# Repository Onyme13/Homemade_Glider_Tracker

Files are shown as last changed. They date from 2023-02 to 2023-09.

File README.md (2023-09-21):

# Homemade Glider Computer (Work in progress)

In the world of light aviation and air sports, gliders occupy a special place because of their dependence on the weather and their ability to slide silently across the skies. To improve the flying experience of gliders and provide pilots with essential data in real time, My bachelor’s degree research project in Information Systems and Service Science focused on the design and implementation of a prototype homemade flight tracker specifically designed for these aircraft.

**WARNING: PROTOTYPE**

This device is an experimental prototype and should only be used for testing purposes. It is not intended for flight-critical applications or navigation. Use at your own risk. The creator is not responsible for any accidents or damages resulting from its use. Prioritize safety and follow all aviation regulations during testing.

## Installation

**Step 1: Gather the Required Materials**

Before starting the installation process, make sure you have all the necessary materials and components for your homemade glider computer. These may include:

1. Raspberry Pi Zero W (the WiFi model in important for ssh connection for future installations)
2. MicroSD card (at least 32GB)
3. Arduino Micro without headers
4. GPS Module
5. Antenna for the GPS module (not mandatory)
6. Barometric sensor
7. Display (TFT screen 3.5")
8. PiSugar Battery for Raspberry Pi-Zero W/WH 1200 mAh
9. Cables and connectors
10. micro-USB to micro-USB cable
11. Case to mount the components securely (Can be 3D printed).
    You can find the .stl file for the case and the cover on this repository.
(12. Two 2mm screws for closing the case, if 3D printed)

See the [Required Materials](https://github.com/Onyme13/Homemade_Glider_Tracker/tree/main/Documentation) for more informations about all the necessary materials.

**Step 2: Set Up the Raspberry Pi**

For more information. Follow the [Manuel_de_reproduction_FR.pdf](https://github.com/Onyme13/Homemade_Glider_Tracker/blob/main/Documentation/Manuel_de_reproduction_FR.pdf) for more details. Pages 6 to 11

1. Download the latest Raspberry Pi OS Imager from the official website.
2. Flash the OS image onto a microSD. In the Advanced option, enable SSH for remote connection. It is the only way to access to the Pi.
3. Download Advanced IP Scanner from the official website.
4. Download PuTTY - a free SSH and telnet client for Windows. (Or any other SSH solution)
5. Download FileZilla - The free File Transfert Protocol solution. You need this to upload your GPS map to the Pi.
5. Setup the Raspeberry Pi OS . Follow the [Manuel_de_reproduction_FR.pdf] guide. Pages 7 to 10
6. Insert the microSD card into the Raspberry Pi.

**Step 3: Install Required Software on the Raspberry PI using SSH**

For more information. Follow the [Manuel_de_reproduction_FR.pdf](https://github.com/Onyme13/Homemade_Glider_Tracker/blob/main/Documentation/Manuel_de_reproduction_FR.pdf) for more details. Pages 12 to 17

(This is probably the longest step of the installation)

1. Power up the Raspberry Pi.

2. Scan all the IP's from your network with Advanced IP Scanner so you can the Raspberry Pi's IP address.

3. With the now found IP adress. Connect to your Raspberry Pi through SSH with PuTTY. 

4. Update the Raspberry Pi OS by running:
   ```
   sudo apt-get update
   sudo apt-get upgrade
   ```

5. Clone the git repository by running.
    ```
    git clone https://github.com/Onyme13/Homemade_Glider_Tracker.git
    ```
6. Install Pip and go in to the file. After installation of pip, you can verify that pip is installed:
    ```
    sudo apt install python3-pip
    pip --version
    ```

   Then install the needed python libraries:

    ```
    cd Research-Project
    sudo python -m pip install -r requirements.txt
    ```    

7. File transfert the map zipped file using FileZilla (this step can take more than hour).

8. Unzip the file by running on the Raspberry Pi (this step can take more than hour):
    ```
    sudo apt install unzip
    unzip tile_OSM.zip
    ```
9. Meanwhile configure the screen by activating SPI connection on the Pi and disable Sleep Mode , run:
    ``` 
    sudo raspi-config
    ```
10. Navigate to Display Options, and press enter.
11. Navigate to the 4th line, Screen Blanking. Press Enter and select No. [link](https://raspberrytips.com/disable-sleep-mode-raspberry-pi/)
12. Activate the SPI connection on the same menu.
13. Then run:
    ```
    sudo rm -rf LCD-show
    git clone https://github.com/MrYacha/LCD-show.git
    chmod -R 755 LCD-show
    cd LCD-show/
    ```
    and 
    ```
    sudo ./LCD35-show
    ```
    The Pi will reboot, the screen should be correctly configured

**Step 4: Set Up the Microcontroller Arduino Micro**

1. Download the Arduino IDE from the official website
2. Connect your microcontroller to your computer with USB
3. Upload the Arduino_Double_Sensor.ino from this repository on the Arduino Micro with the Arduino IDE using your computer.

**Step 5: Assemble the Components**
Carefully solder all the connectors following the schema. Adapt the cabling according to your components.

Follow the [Manuel_de_reproduction_FR.pdf](https://github.com/Onyme13/Homemade_Glider_Tracker/blob/main/Documentation/Manuel_de_reproduction_FR.pdf) steps.

Double-check the schema (wiring diagram) to ensure you have a clear understanding of how the connectors should be soldered. The schema will show the connections between different components, such as sensors, displays, and microcontrollers.

Carefully mount the Raspberry Pi, microcontroller, sensors, display, and other components inside the case. 

**Step 6: Test the Glider Computer Software**

Verify that the software is working as expected. Make sure the data from sensors are accurate, the display shows the relevant information correctly, and the system behaves as intended.

**Step 7: Test the Glider Computer**

ALWAYS PRIORITIZE THE FLIGHT SAFETY.
KEEP YOUR EYES OUT OF THE PLANE.

Before the actual glider flight, do some ground tests to confirm that the glider computer works as expected. Once you're confident in its functionality, conduct a test flight to see how it performs during actual gliding.

**Step 8: Monitor and Improve**

ALWAYS PRIORITIZE THE FLIGHT SAFETY.
KEEP YOUR EYES OUT OF THE PLANE.

During and after the flight, closely monitor the glider computer's performance. Take note of any issues or improvements that can be made to enhance its functionality or accuracy.

Remember to always prioritize safety and adhere to local regulations.

## Contributing

Thank you for considering contributing to Homemade Glider Computer! I welcome contributions from the community and appreciate your support in making this project better.

1. Clone the repository

2. Make Changes

Make your desired changes and improvements to the codebase. Please ensure that your changes adhere to the project's coding standards and guidelines.

3. Test your Changes

Before submitting a pull request, make sure to test your changes thoroughly to ensure they work as intended and do not introduce any new issues.ct.

4. Commit your changes

5. Code Review

Your pull request will undergo a code review by the project maintainers. Be prepared to make additional changes based on feedback.

6. Merge

Once your pull request is approved and any necessary changes are made, it will be merged into the main project.

Thank you for your valuable contributions!

## License

This work is licensed under the Creative Commons Attribution-NonCommercial 4.0 International License. To view a copy of this license, visit https://creativecommons.org/licenses/by-nc/4.0/ or send a letter to Creative Commons, PO Box 1866, Mountain View, CA 94042, USA.

## Contact

For any questions, feel free to contact me at this email adress: jocorl@hotmailch

## Photos

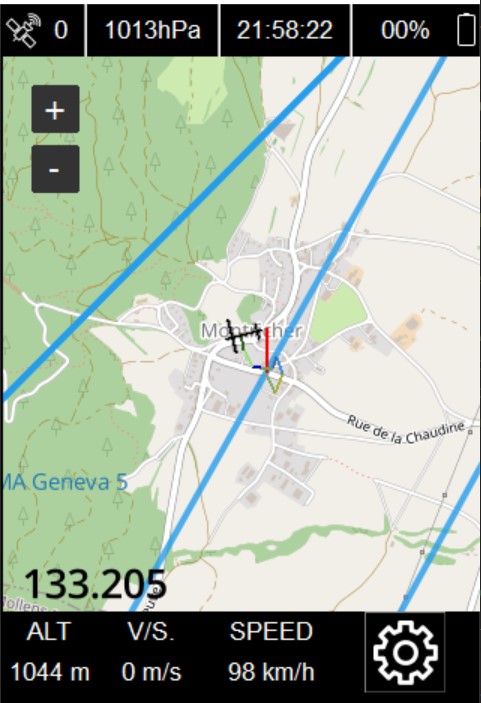
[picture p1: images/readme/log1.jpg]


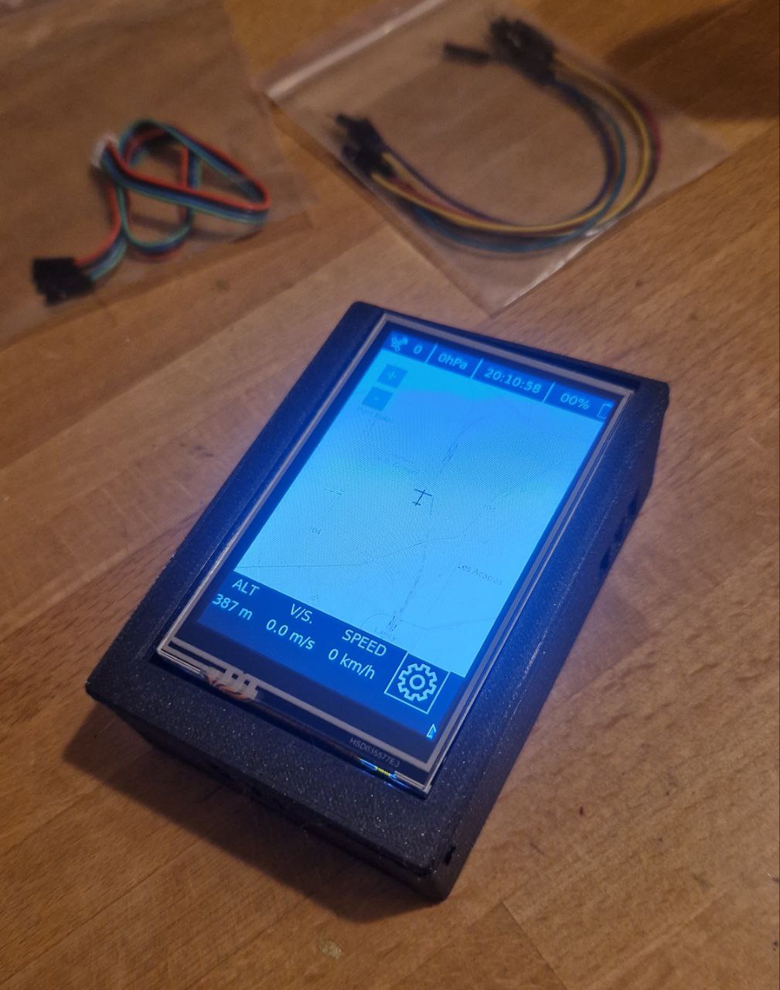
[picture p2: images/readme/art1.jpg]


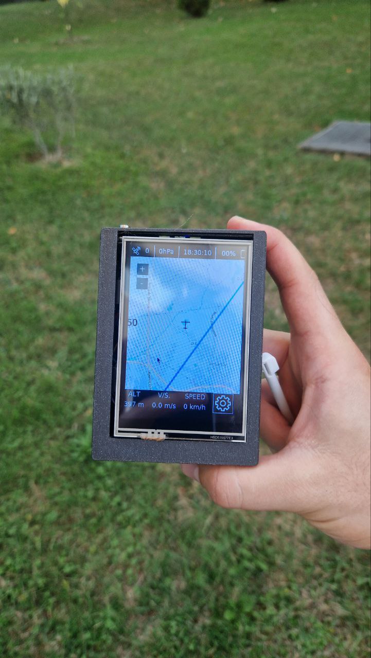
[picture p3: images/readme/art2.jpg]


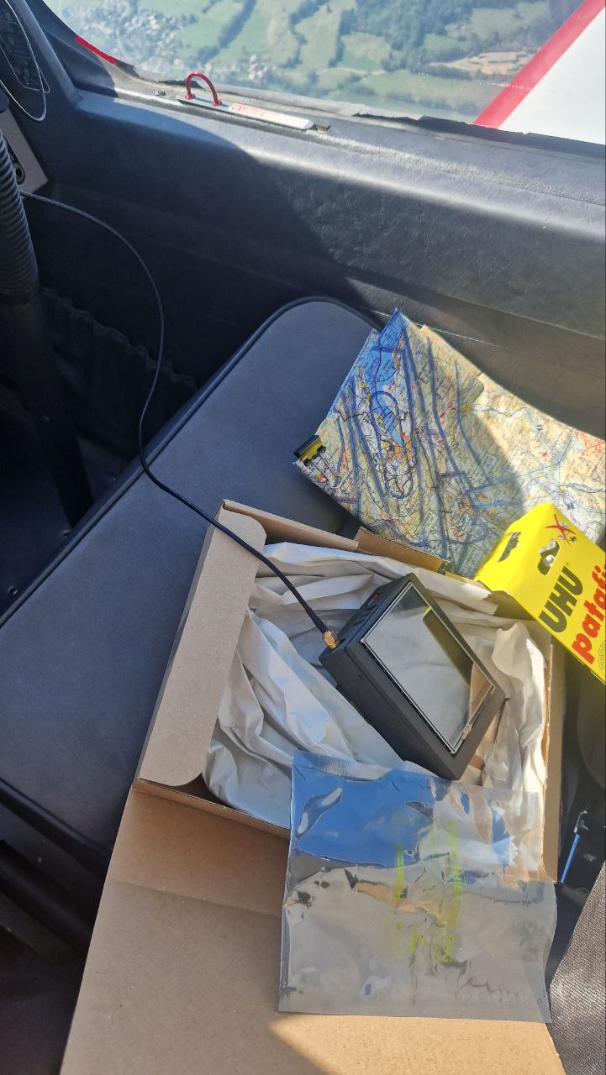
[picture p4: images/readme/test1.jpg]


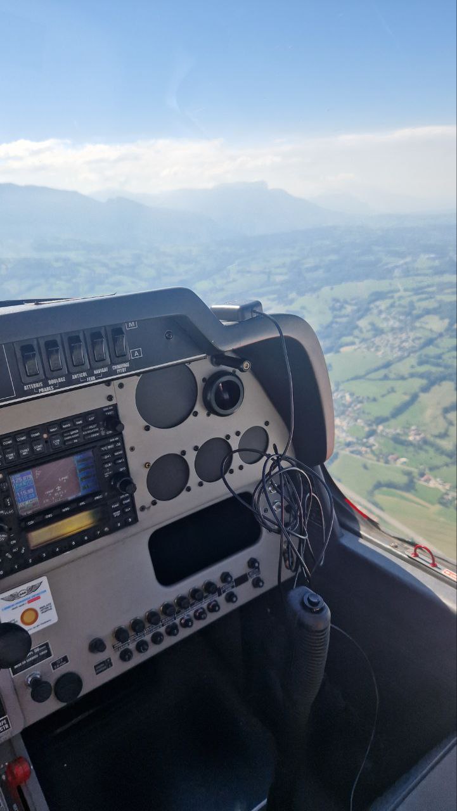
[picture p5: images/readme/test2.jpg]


## Further Reading

FacLab articles
1. [Développement d'un Tracker de Vol Fait Maison pour Planeurs](https://faclab.ch/publication/developpement-dun-tracker-de-vol-fait-maison-pour-planeurs)
2. [Tests et conclusion du travail de Bachelor du Tracker de Vol Fait Maison pour Planeurs](https://faclab.ch/publication/tests-et-conclusion-du-travail-de-bachelor-du-tracker-de-vol-fait-maison-pour-planeurs)

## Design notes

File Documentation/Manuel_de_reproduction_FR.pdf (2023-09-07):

# Manuel de reproduction tangible du tracker de vol à voile fait maison

# INDEX

Contenus

# Introduction

Dans le monde de l'aviation légère et des sports aériens, les planeurs occupent une place particulière en raison de leur dépendance à la météo et de leur capacité à glisser silencieusement à travers les cieux. Pour améliorer l'expérience de vol des planeurs et fournir aux pilotes des données essentielles en temps réel, mon projet de recherche de fin de bachelor en systèmes d’information et science des services s'est concentré sur la conception et la mise en œuvre d'un prototype de tracker de vol fait maison spécialement conçu pour ces aéronefs.

Les trackers de vol traditionnel que l’on trouve sur le marché sont relativement coûteux. Le prix de ces appareils se situe autour des 700 francs suisses. Grâce à la démocratisation des microcontrôleurs et microordinateur, ce travail de recherche se base sur la faisabilité de création d’un suiveur de vol fait maison.

Il faut avant tout commencé par choisir les composants appropriés, en tenant compte de facteurs tels que la taille, le poids, la consommation d'énergie et le prix. Les principaux éléments du tracker comprenaient un récepteur GPS, un baromètre et une unité centrale qui traite et stocke les données.

Ce manuel vous fournira les informations essentielles, les instructions détaillées et les astuces pratiques nécessaires pour mener à bien votre projet.

Dans les pages qui suivent, vous découvrirez les procédures étape par étape pour vous guider dans la réalisation du tracker de vol. Vous y trouverez des schémas, des illustrations, des listes de matériaux, et tout ce dont vous avez besoin pour reproduire.

Pour la partie code, référez vous au repo Git ci-dessous.

Lien du GitHub : https://github.com/Onyme13/Homemade_Glider_Tracker.git

# Préparation du Raspberry Pi Zero W

## Matériel

### 1. Raspberry Pi Zero W avec en-têtes (le modèle wifi est indispensable)

### 2. Carte microSD de 32Go minimum

## 1. Téléchargement des logiciel et le fichier requis sur votre PC

1.1 Advanced IP Scanner. Ce programme affiche toutes adresse IP des périphériques sur votre réseau :

https://www.advanced-ip-scanner.com/

1.2 Raspberry Pi Imager. Raspberry Pi Imager est le moyen rapide et facile d’installer Raspberry Pi OS sur une carte microSD, prête à l’emploi avec votre Raspberry Pi :

https://www.raspberrypi.com/software/

1.3 PuTTY. Ce programme est un client SSH principalement utilisé pour se connecter à distance à des systèmes informatiques:

https://www.putty.org/

1.4 FilleZilla Client. C’est un programme de transfert de fichiers qui permet aux utilisateurs de gérer et de transférer des fichiers entre leur ordinateur local et une machine distante :

https://filezilla-project.org/

### 1.5 Téléchargement de carte sur Google Drive :

https://drive.google.com/file/d/1Afhucx_kdtul0cSf0_6vRhANw7dOtnIN/view?usp=sharing

## 2. Installation Raspberry Pi OS

2.1 Insérez la carte SD dans le lecteur de carte de votre ordinateur.

2.2 Ouvrir le logiciel Raspverry PI OS.

### 2.3 Choisir le bon OS

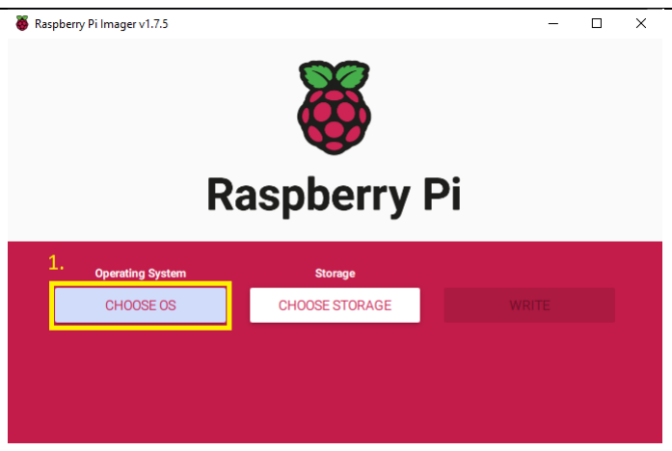
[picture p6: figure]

### 2.4 Choisir la carte microSD comme stockage

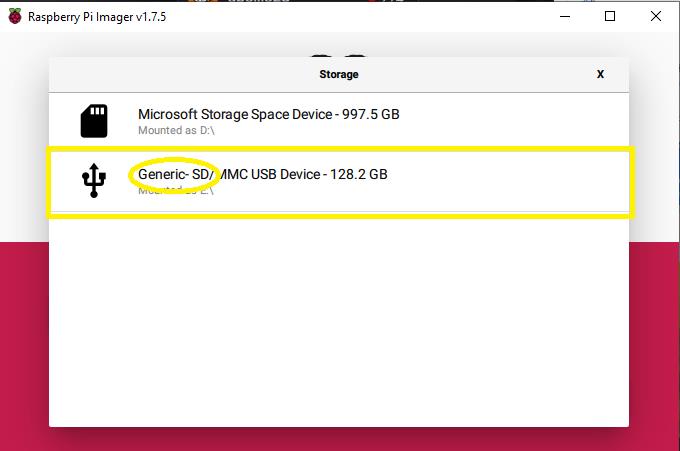
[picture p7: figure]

### 2.5.1 Configuration de l’OS

### 2.5.2 Activer le SSH et ajouter un Username et mot de passe

Sauvegarder l’identifiant et mot de passe pour l’étape Installation du logiciel sur Raspberry PI

### 2.5.3 Configurer la connexion au WiFi

1.Activer la connexion wLAN
2.Sélectionner le réseau local. Attention, le Raspberry Pi ne connecte pas au réseau de 5GHz
3.Entrer le mot du passe du réseau

### 2.5. Installer l’OS

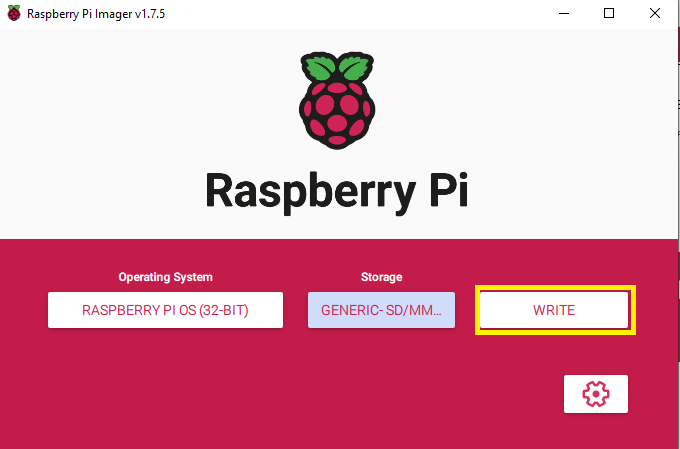
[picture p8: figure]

# Installation du logiciel sur le Raspberry PI

## 1. Insérer la carte microSD dans le Raspberry Pi

## 2. Allumer le Raspberry Pi

## 3. Trouver l’IP du Raspberry Pi

### 3.1 Lancer le scan avec Advanced IP Scanner

### 3.2 Copier l’IP du Raspberry PI

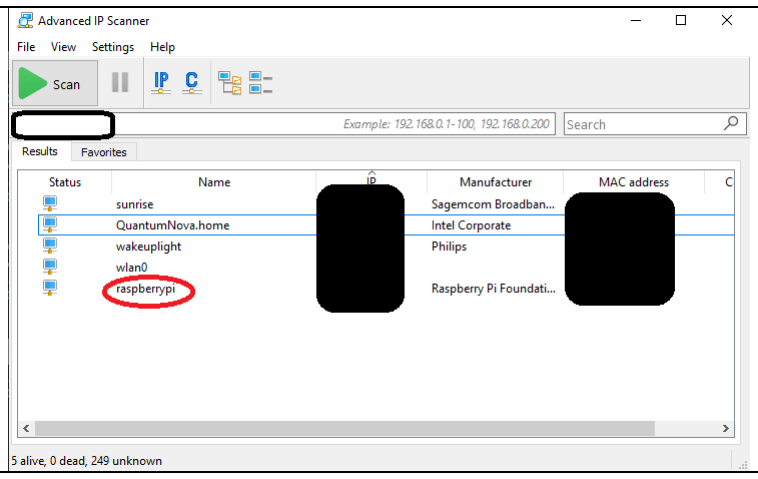
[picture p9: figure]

## 4. Connection via SSH

### 4.1 Ouvrir puTTY.exe

### 4.2 Connection au Raspberry Pi

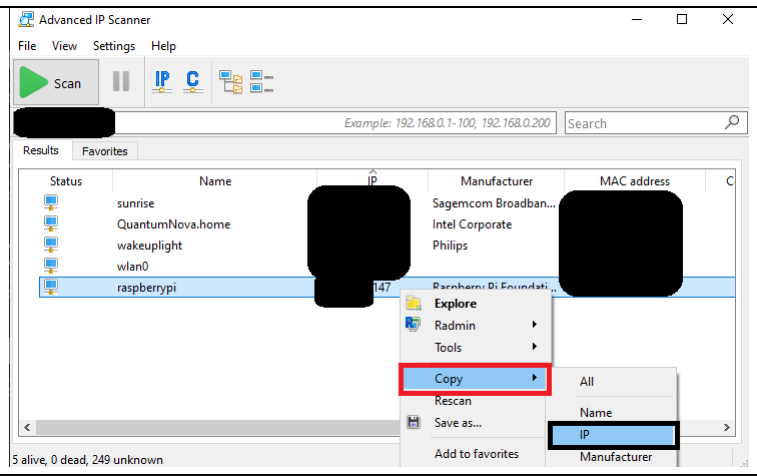
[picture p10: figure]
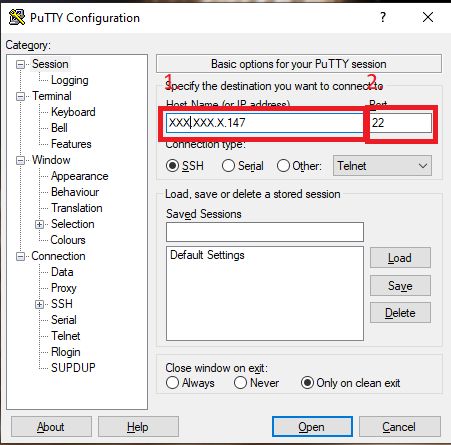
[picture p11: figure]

1. Coller l’IP du Raspberry Pi
2. Port 22 nécessaire

## 5. Téléchargement du logiciel

### 5.1 Connection au Raspberry avec les identifiants de l’étape Préparation du Raspberry Pi

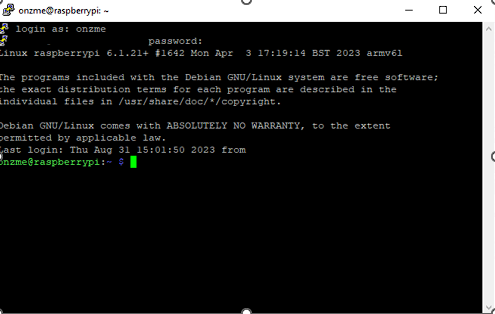
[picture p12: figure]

### 5.2 Mettre à jour le Raspberry Pi OS en exécutant

sudo apt-get update
sudo apt-get upgrade

### 5.3 Cloner le git repository en exécutant

git clone https://github.com/Onyme13/Homemade_Glider_Tracker.git

5.4 Installer Pip et aller dans le fichier et installer toutes les bibliothèques python nécessaires en exécutant :

sudo apt install python3-pip pip –version

5.5 Après l’installation de pip, vous pouvez vérifier que pip est installé. Ensuite, installez les bibliothèques python nécessaires

cd Homemade_Glider_Tracker sudo python -m pip install -r requirements.txt

5.6 Transférez le fichier zippé de la carte à l’aide de FileZilla.
Drag and Drop le dossier de la carte zippé de l’étape Préparation du Raspberry Pi

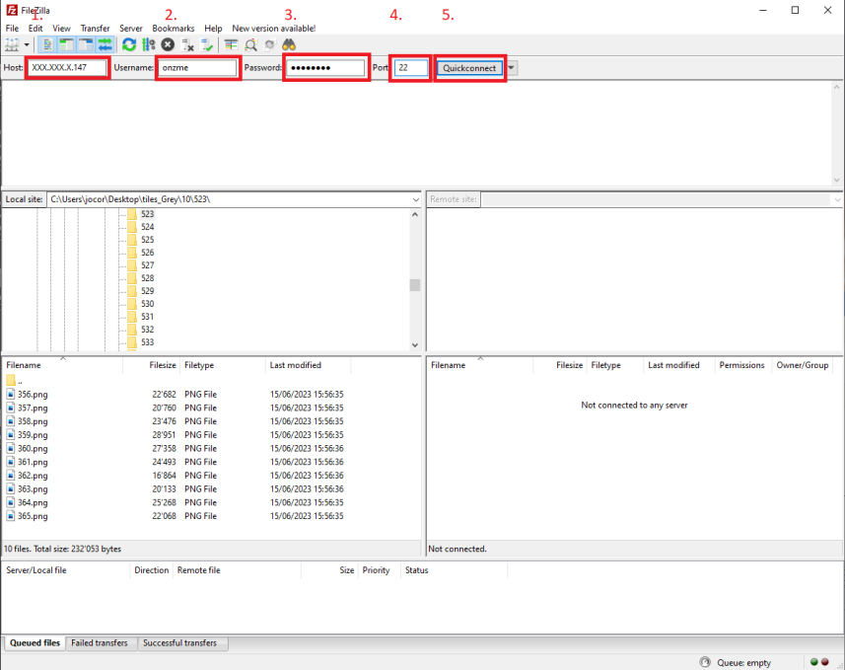
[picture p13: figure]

1. IP du Raspberry PI
2. Identifiant
3. Mot de passe
4. Port 22
5. Connection

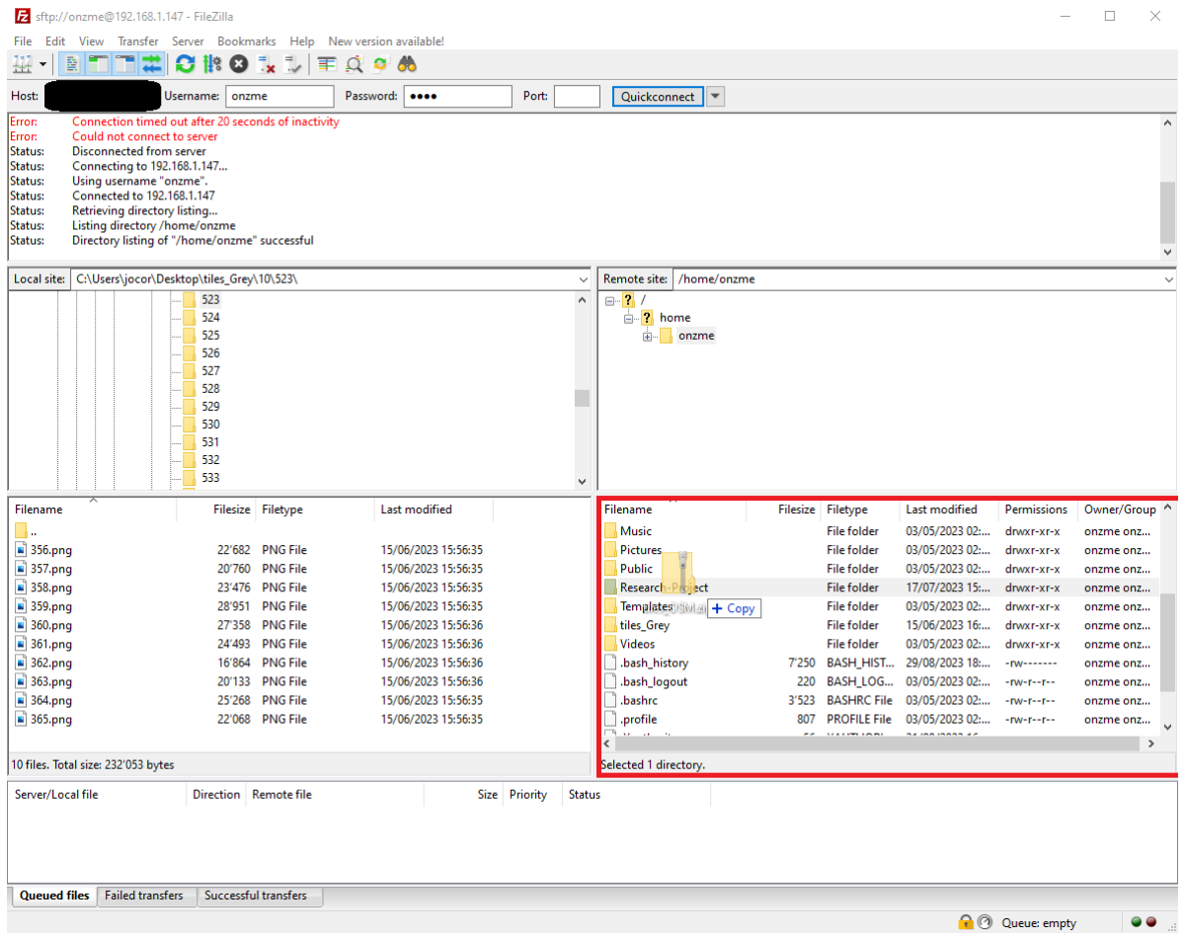
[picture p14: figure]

### 5.7 Décompressez le fichier en l’exécutant sur le Raspberry Pi en exécutant :

sudo apt install unzip
unzip tiles_OSM.zip

## 6. Activation du Touchscreen

### 6.1 Activer les connecteurs SPI

sudo raspi-config

6.2 Installer les fichiers nécessaire pour l’écran.

sudo rm -rf LCD-show
git clone https://github.com/MrYacha/LCD-show.git cd LCD-show
chmod LCD35-show

6.3 Finalement, le Raspberry Pi va redémarrer.

sudo ./LCD35-show

## 7. Ajout d’icône de lancement du logiciel sur le Desktop du Raspberry

Pi

### 7.1 Copie des données de l’icône sur le chemin du Desktop

cp Homemade_Glider_Tracker/launch.desktop ~/Desktop/

### 7.2 Ajout des droits d’exécution du script

sudo chmod +x Homemade_Glider_Tracker/startup.sh

# Assemblage du suiveur de vol

## Matériel

1. Module GPS - Whadda WPI430 Module GPS U-BLOX NEO-7M

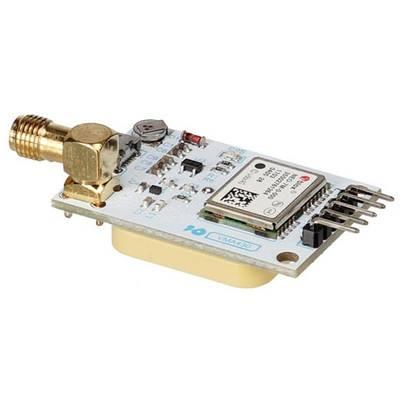
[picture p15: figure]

2. Module Baromètre - DFRobot Gravity BMP388 Capteur de pression barométrique

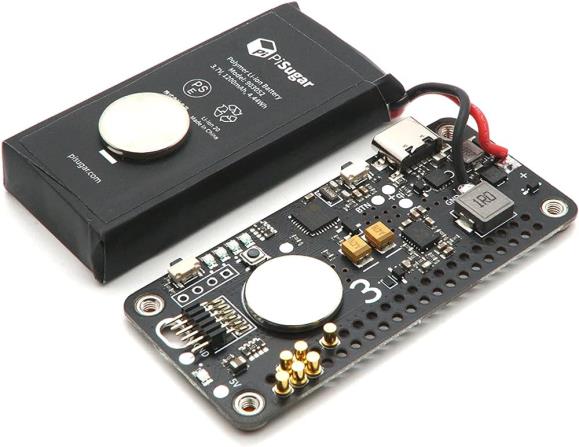
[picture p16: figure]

3. Batterie PiSugar - PiSugar Pwnagotchi Batterie au lithium pour Raspberry Pi-Zero W/WH 1200 mAh

4. Arduino Micro (sans les pins/headers)
5. Câbles DuPont

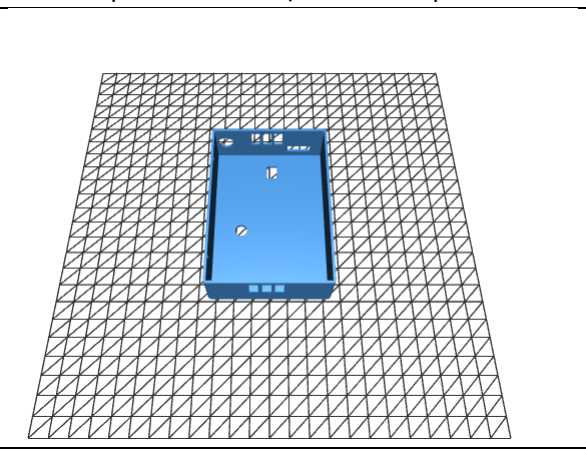
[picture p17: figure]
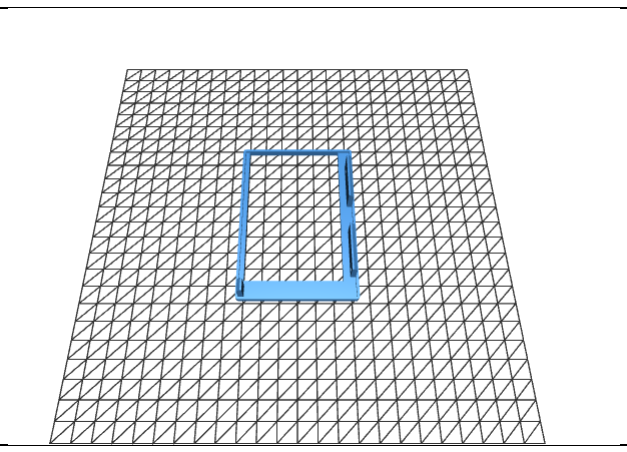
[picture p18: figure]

6. Boîter imprimer en 3D (voir les étapes suivantes)

## 1.Impression du boîter et de son couvercle en 3D

Fichier STL pour l’impression

- Boîtier :
https://github.com/Onyme13/Homemade_Glider_Tracker/blob/main/3D%20STL%20file/case%20v0. 2.stl (https://github.com/Onyme13/Homemade_Glider_Tracker/blob/main/3D%20STL%20file/case%20v0.2.stl)
- Couvercle :
https://github.com/Onyme13/Homemade_Glider_Tracker/blob/main/3D%20STL%20file/cover%20v0 .4.stl (https://github.com/Onyme13/Homemade_Glider_Tracker/blob/main/3D%20STL%20file/cover%20v0.4.stl)

## 2. Assemblage des câbles du Dupont sur le module GPS

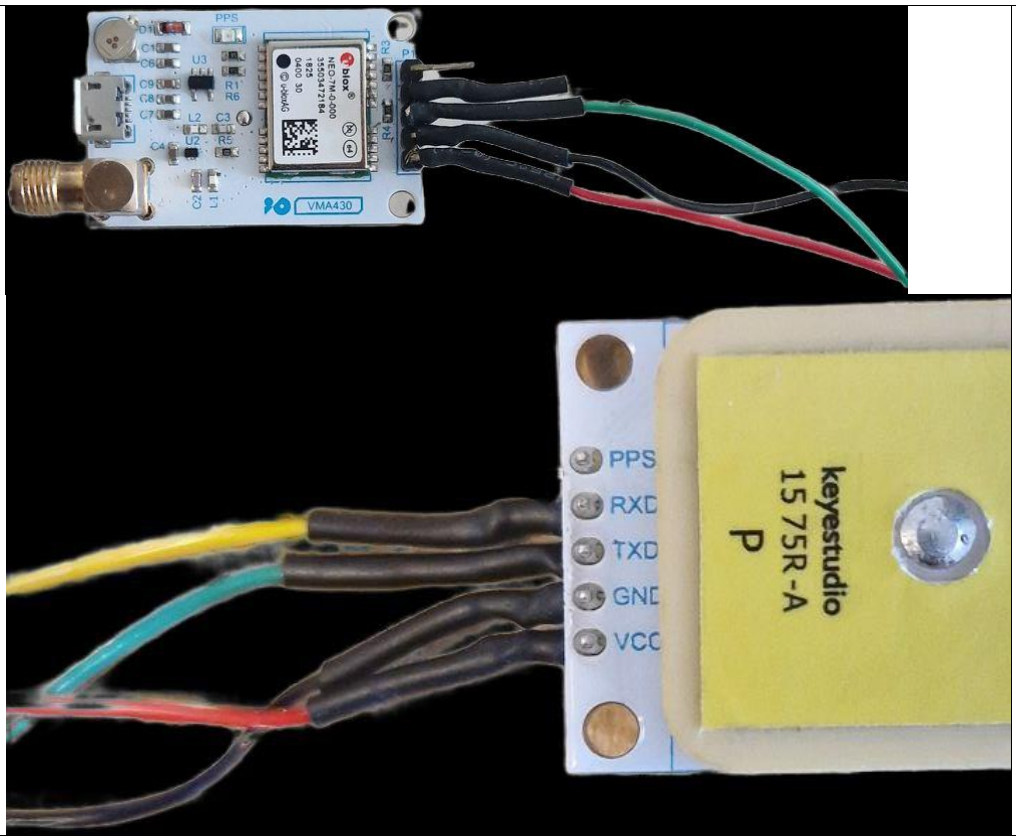
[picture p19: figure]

- RXD transmission câble jaune
- TXD transmission câble vert
- GND prise de terre câble noir
- VCC entrée 5 v câble rouge

## 3. Assemblage des câbles du Dupont sur le module barométrique

Souder les câbles Dupont aux entrées :
- VCC
- GND
- SDO
- CSB
- SDI
- SCK

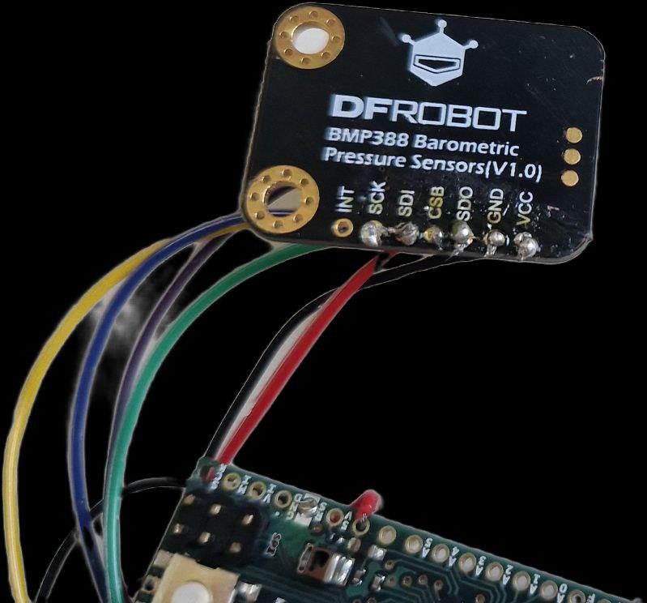
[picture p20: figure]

## 4. Assemblage des câbles du GPS et baromètre au Arduino Micro

Souder les câbles du GPS et du baromètres au Arduino Micro comme suit :

Baromètre :
- VCC → +3.3V
- GND → GND
- SDO → 12
- CSB → 10
- SDI → 11
- SCK → 13

Module GPS :

- VCC → +5V
- GND → GND
- RXD → 9
- TXD → 8

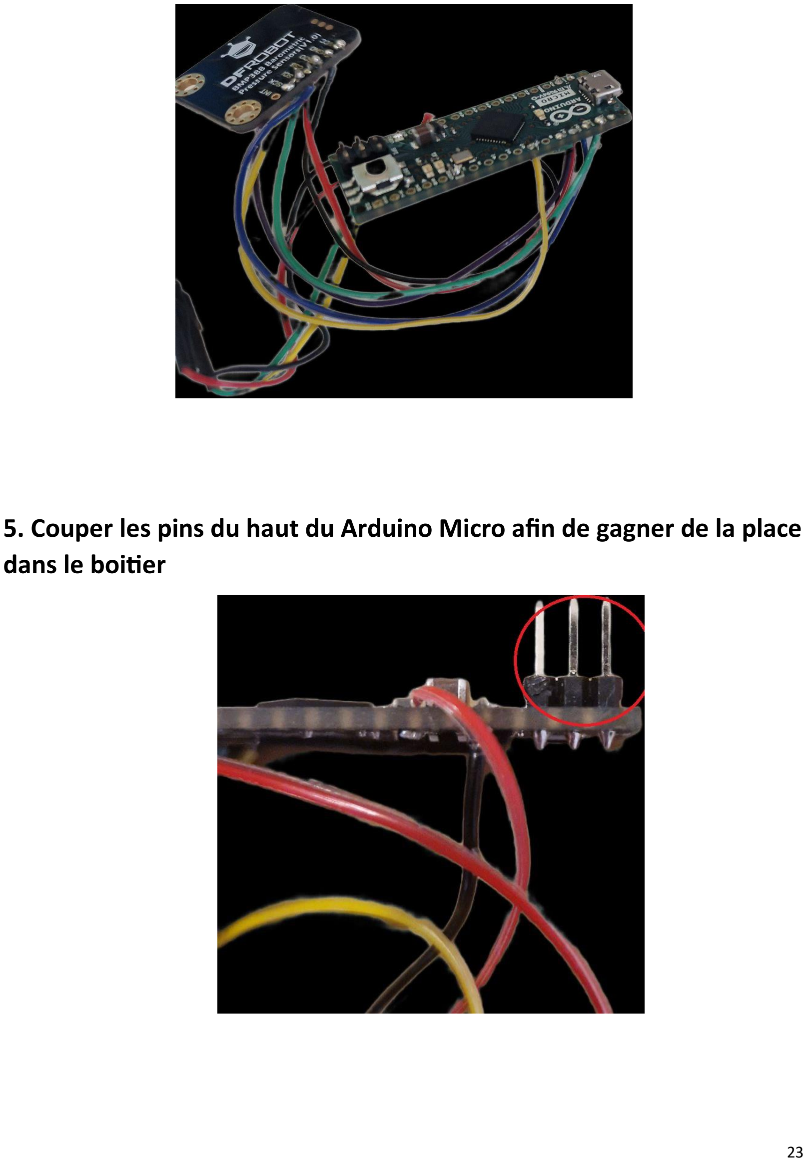
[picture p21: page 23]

## 5. Couper les pins du haut du Arduino Micro afin de gagner de la place dans le boitier

## 6.Branchez la batterie PiSugar sur le Raspberry Pi à l’aide des quatre vis fournies

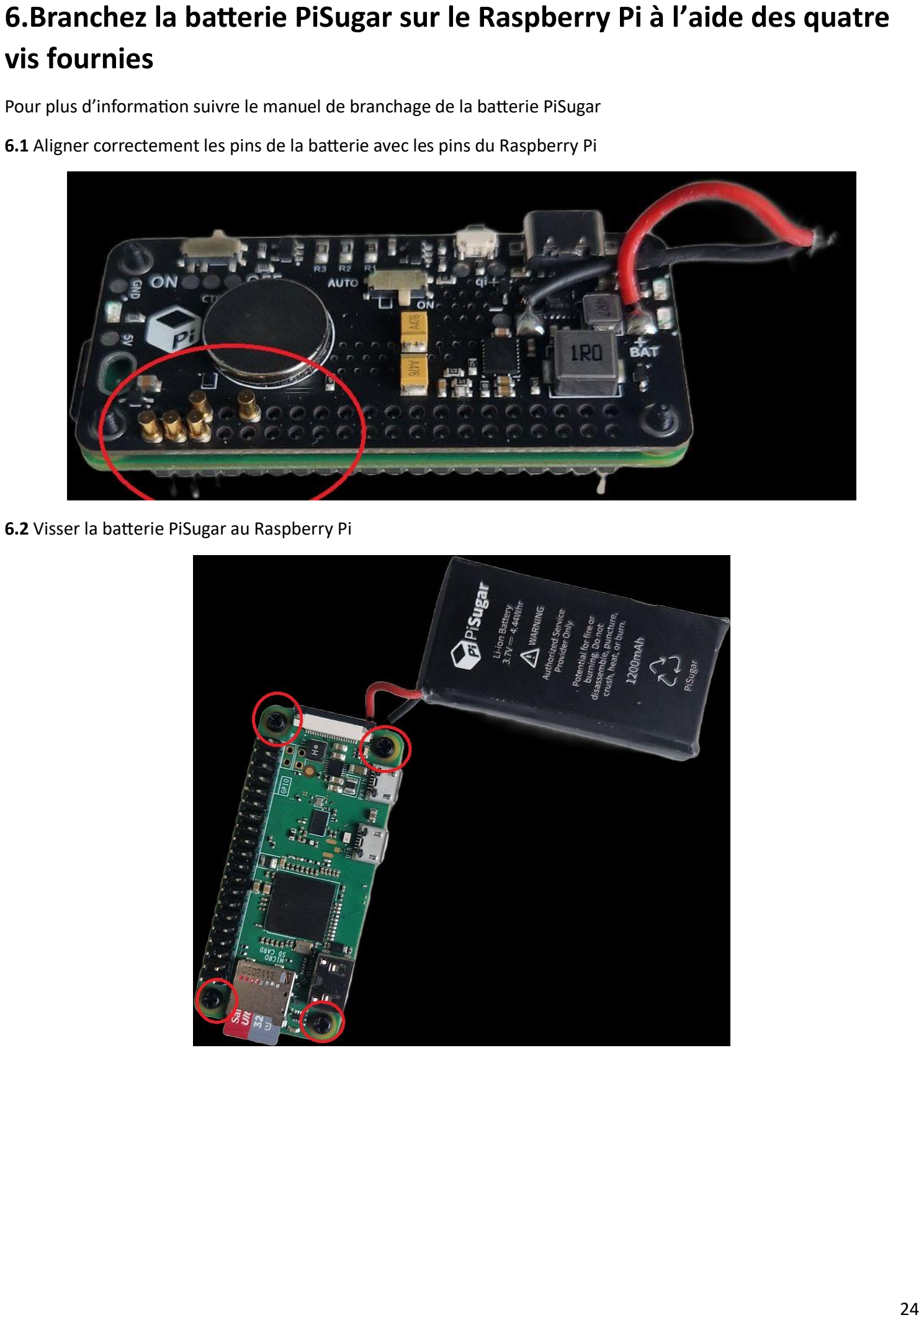
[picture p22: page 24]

Pour plus d’information suivre le manuel de branchage de la batterie PiSugar

### 6.1 Aligner correctement les pins de la batterie avec les pins du Raspberry Pi

### 6.2 Visser la batterie PiSugar au Raspberry Pi

## 7.Brancher le câble microUSB au Arduino Micro à l’entrée microUSB du Raspberry Pi Zero

## 8.Insérez délicatement le tout dans le boîter imprimé en 3D

8.1 Insérez en premier le Raspberry Pi Zero avec PiSugar et le câble microUSB comme suit. La carte microSD doit sortir par l’ouverture prévue à cette effet.

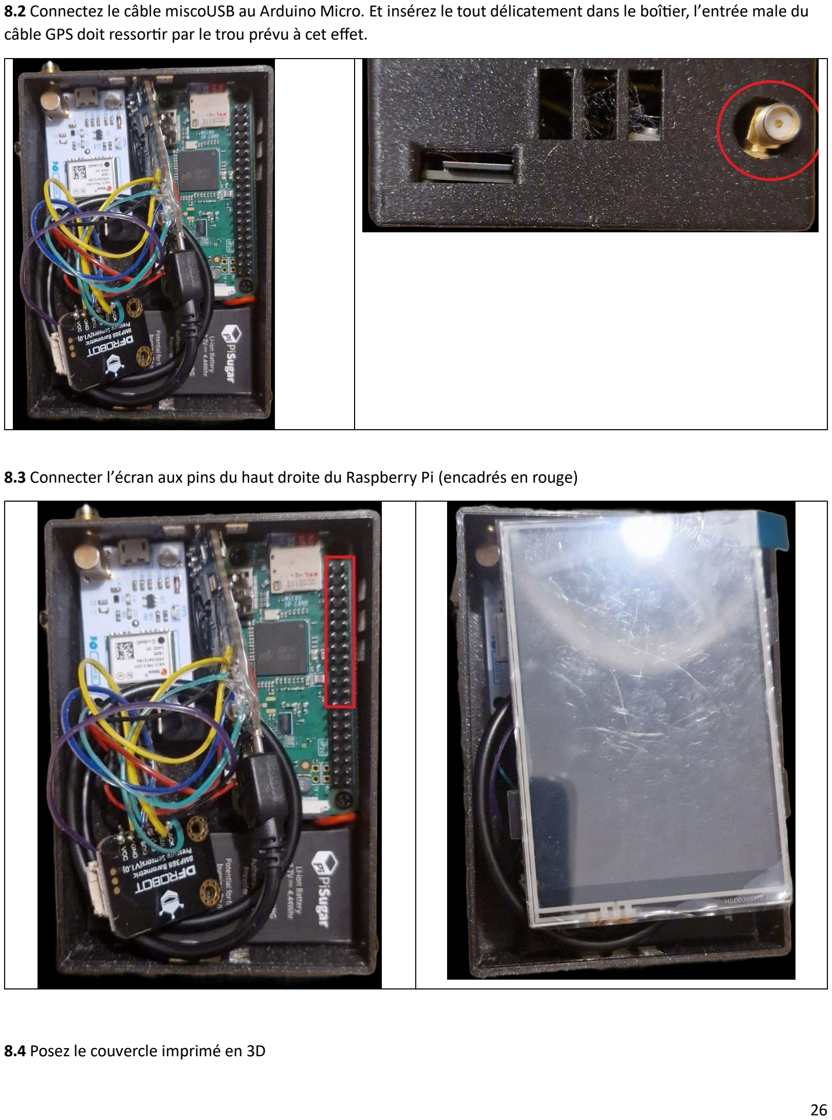
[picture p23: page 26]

8.2 Connectez le câble miscoUSB au Arduino Micro. Et insérez le tout délicatement dans le boîtier, l’entrée male du câble GPS doit ressortir par le trou prévu à cet effet.

### 8.3 Connecter l’écran aux pins du haut droite du Raspberry Pi (encadrés en rouge)

### 8.4 Posez le couvercle imprimé en 3D

## 9.Visez les deux vis sur le côté du boîtier

Sur le côté gauche et droite. Il faut des vis de 2mm de diamètre et pas plus de 6mm de longueur

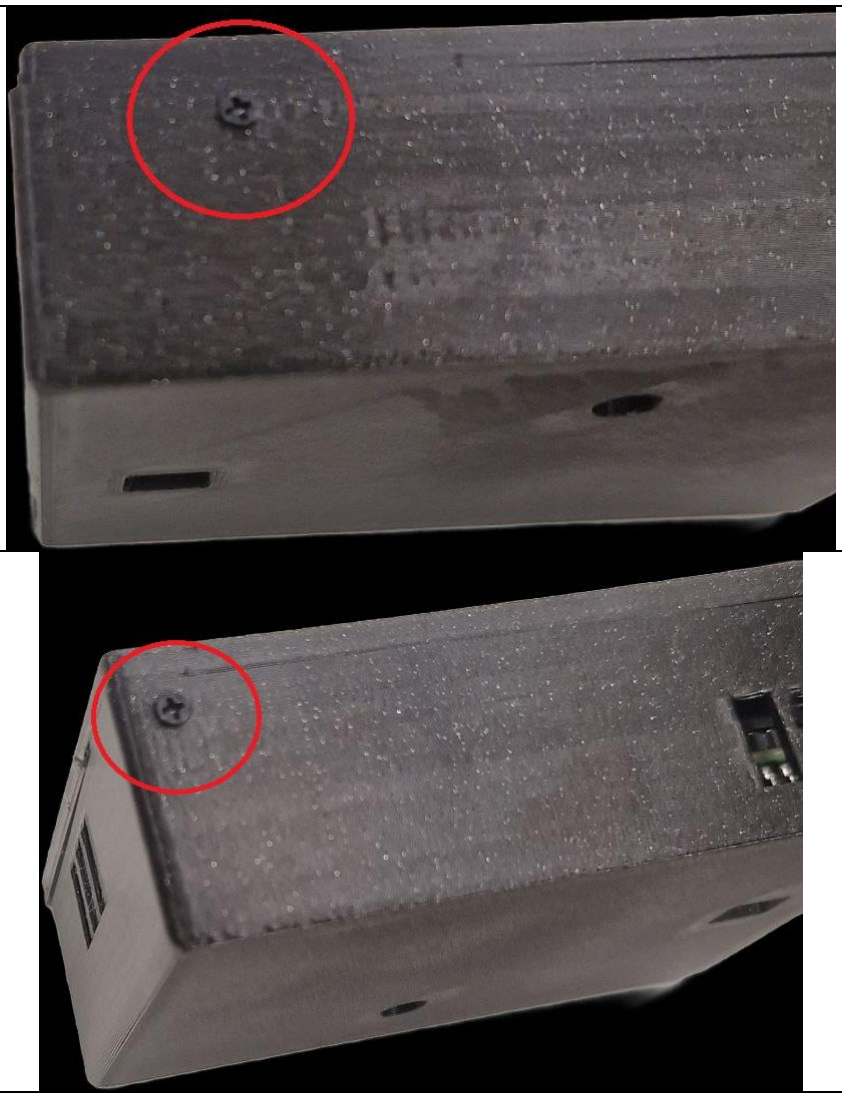
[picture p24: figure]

# Récupération des données de vols

## 1. Ouvrir FileZilla sur votre PC 2. Connection l’IP du Raspberry Pi avec ses identifiants 3. Drag and Drop le fichier d’enregistrement. Il se trouve dans Homemade_Glider_Tracker/data/mouvement_[YYYY-MM-DD].csv

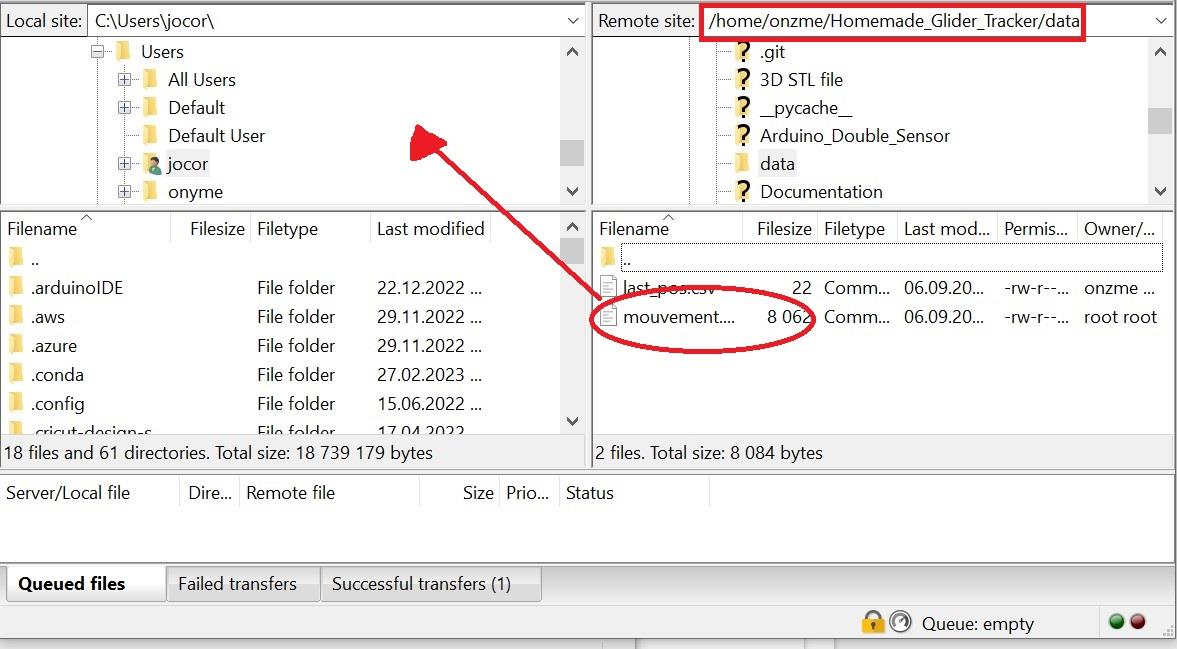
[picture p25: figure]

# Tests

## 1er Test : À Pied

Le premier test à pied est un succès. Bien que le chemin tracé par le GPS ne soit pas particulièrement long, cela s'explique par la faible vitesse de déplacement de seulement 5 km/h. De manière attendue, la vitesse verticale n'a pas varié durant ce test, ce qui est tout à fait conforme aux attentes. Le GPS fonctionne malgré le fait qu’il a été testé en zone urbaine (Petit-Lancy). Les immeubles d’habitations pourraient bloquer la plupart des satellites de réception, mais le chemin est indiqué par le GPS est fidèle à la réalité du trajet du test.

Le trajet indiqué sur la photo de l’écran est court, mais le logiciel est calibré pour des parcours sur des grandes distances. Ce dernier mets à jour la position du planeur uniquement lorsqu’un certain seuil est dépassé.

Nous pouvons voir que les positions GPS sont réparties par « clusters ». Le fait que le test a été réaliser en zone urbaine pourrait expliquer cela. Les immeubles d’habitations auraient pu bloquer quelques signaux satellites.

Ces résultats confirment la précision et la fiabilité du GPS, même dans des conditions de déplacement à faible vitesse.

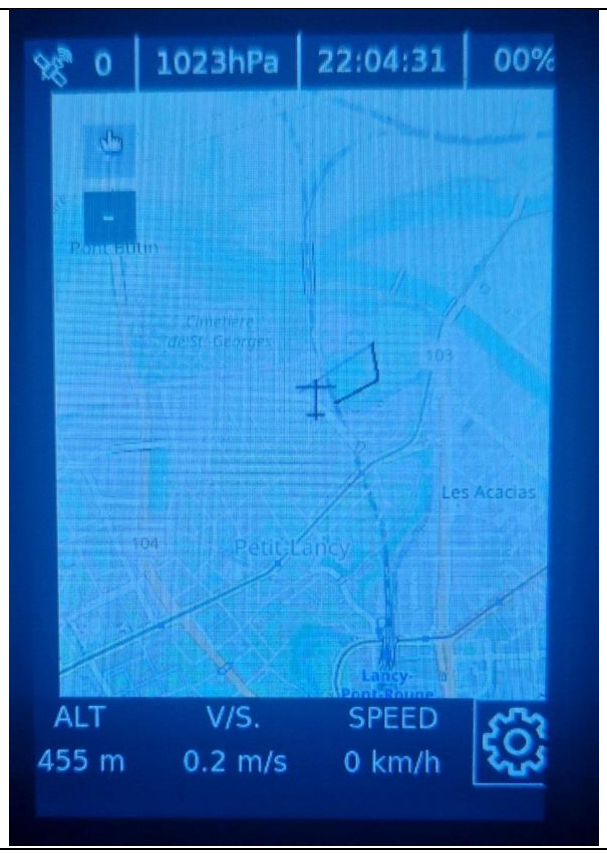
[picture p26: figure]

## 2ème Test : En Vélo

Le test à vélo a produit des résultats similaires, avec un suivi de la position et de l'altitude. Comme pour le test à pied, quelques pertes de signal GPS sporadiques ont été observées. Il est important de souligner que ces perturbations pourraient être attribuées à l'environnement urbain dans lequel le test a été effectué (quartier d’Onex).

Malgré ces perturbations occasionnelles, le tracker a continué à fonctionner de manière fiable dans des conditions exigeantes. Ces résultats prouvent qu’avec une plus grande vitesse, le tracker fonctionne tout de même. Un test en vol est à suivre.

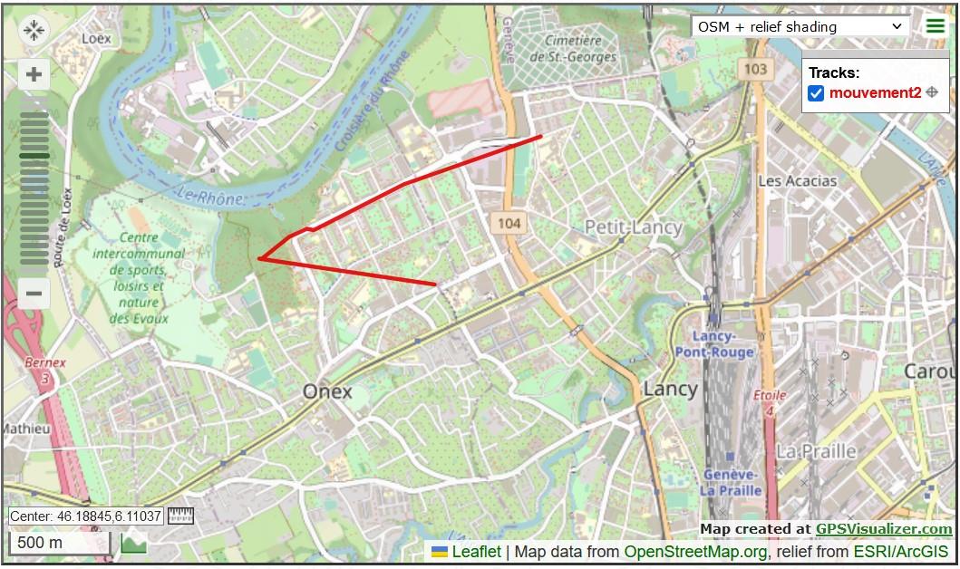
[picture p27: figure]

## 3ème Test : En Avion

La dernière phase de test a placé le tracker de vol dans son élément naturel : l'aviation légère. Intégré à un avion moteur léger, le dispositif a été évalué lors de vols réels en avion.

Lors du test en avion moteur, le tracker de vol a été soumis à une épreuve en survolant depuis l’aérodrome d’Annemasse, la région de la Roche-sur-Foron, puis Bonneville, à une altitude de 5000 pieds. Comme nous pouvons le voir sur le report de l'enregistrement du vol sur GPS Visualizer, il y a eu une perte de signal GPS au-dessus de la Roche-sur-Foron qui n'a été retrouvée par la suite. Cependant, malgré cette perte temporaire de données GPS, l'altimètre du tracker de vol a continué à indiquer avec précision l'altitude actuelle. Il est important de noter que l’indicateur de vitesse vertical du tracker indiquait des résultats justes.

Une explication à la perte de signal GPS pourrait être la vitesse de l'aéronef. En effet, la perte de signal est apparue lorsque l'avion a fini sa montée et s'est mis en vol horizontal stabilisé à 5000 pieds. La vitesse de croisière de l'avion est de 210 km/h. Lorsque l'avion se déplace rapidement, le récepteur GPS peut avoir du mal à maintenir une liaison constante avec les satellites, entraînant ainsi des interruptions du signal. La dernière donnée enregistrée indique 1554 mètre ce qui correspond à environ 5000 pieds (voir image ci-dessous). Ceci pourrait confirmer cette explication.
Cependant, la vitesse de montée de l'avion moteur en question est d'environ de 165 km/h, la vitesse de moyenne d'un planeur tourne autour des 100 km/h. Donc en théorie, le signal ne devrait pas se perdre si le tracker est embarqué dans un planeur.

La calibration automatique de l’altimètre, grâce l’altitude donné par le GPS, est correcte. Celui-ci indiquait une pression de 1020hPa ce qui était la pression du jour dans la région (7 septembre 2023).
Une caractéristique du tracker de vol est sa capacité de calibration. Il utilise les données de l'altitude du GPS en comparant les mesures répétées (environ 20 fois) pour déterminer une altitude fiable, et ainsi une pression atmosphérique locale.
Cette méthodologie de calibration assure une précision optimale dans le suivi de l'altitude, même dans des situations auxquelles la réception GPS peut être intermittente, comme cela a été observé lors du vol au-dessus de la Roche-sur-Foron.

Ces résultats sont très encourageants, car ils montrent que le tracker de vol est équipé pour maintenir des informations cruciales, telles que l'altitude, même en cas de perturbation de la réception GPS.

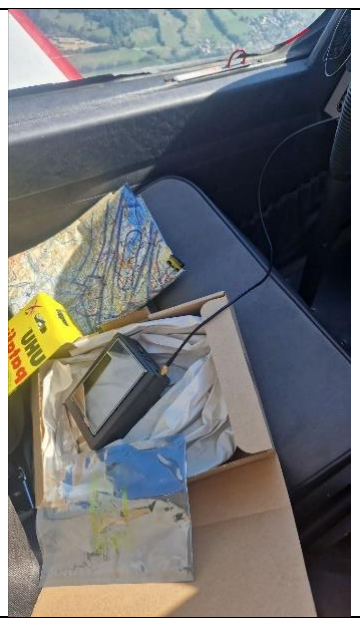
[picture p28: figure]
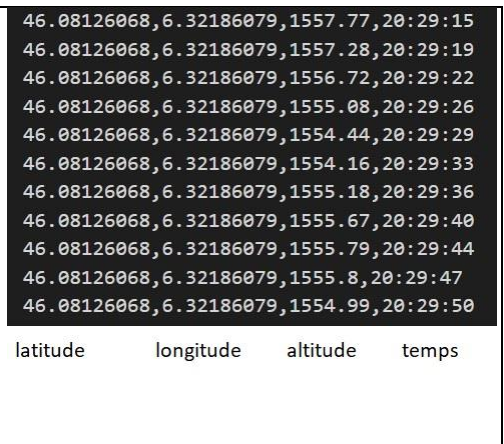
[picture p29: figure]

## Conclusion des Tests

Les phases de test diversifiées ont solidement confirmé la fonctionnalité et la performance du tracker de vol. Qu'il s'agisse du déplacement à pied, à vélo ou en avion, le dispositif a fait preuve d'une collecte de données viables. Le choix des composants, notamment le Raspberry Pi Zero W et l'Arduino Micro, a assuré une flexibilité essentielle.

Les futurs développements se concentreront sur l'optimisation logiciel continue du tracker de vol et sur les pertes de signaux GPS occasionnels.

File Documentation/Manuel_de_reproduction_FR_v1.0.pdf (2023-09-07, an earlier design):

# Manuel de reproduction tangible du tracker de vol à voile fait maison

# INDEX

Contenus

# Introduction

Dans le monde de l'aviation légère et des sports aériens, les planeurs occupent une place particulière en raison de leur dépendance à la météo et de leur capacité à glisser silencieusement à travers les cieux. Pour améliorer l'expérience de vol des planeurs et fournir aux pilotes des données essentielles en temps réel, mon projet de recherche de fin de bachelor en systèmes d’information et science des services s'est concentré sur la conception et la mise en œuvre d'un prototype de tracker de vol fait maison spécialement conçu pour ces aéronefs.

Les trackers de vol traditionnel que l’on trouve sur le marché sont relativement coûteux. Le prix de ces appareils se situe autour des 700 francs suisses. Grâce à la démocratisation des microcontrôleurs et microordinateur, ce travail de recherche se base sur la faisabilité de création d’un suiveur de vol fait maison.

Il faut avant tout commencé par choisir les composants appropriés, en tenant compte de facteurs tels que la taille, le poids, la consommation d'énergie et le prix. Les principaux éléments du tracker comprenaient un récepteur GPS, un baromètre et une unité centrale qui traite et stocke les données.

Ce manuel vous fournira les informations essentielles, les instructions détaillées et les astuces pratiques nécessaires pour mener à bien votre projet.

Dans les pages qui suivent, vous découvrirez les procédures étape par étape pour vous guider dans la réalisation du tracker de vol. Vous y trouverez des schémas, des illustrations, des listes de matériaux, et tout ce dont vous avez besoin pour reproduire.

Pour la partie code, référez vous au repo Git ci-dessous.

Lien du GitHub : https://github.com/Onyme13/Homemade_Glider_Tracker.git

# Préparation du Raspberry Pi Zero W

## Matériel

### 1. Raspberry Pi Zero W avec en-têtes (le modèle wifi est indispensable)

### 2. Carte microSD de 32Go minimum

## 1. Téléchargement des logiciel et le fichier requis sur votre PC

1.1 Advanced IP Scanner. Ce programme affiche toutes adresse IP des périphériques sur votre réseau :

https://www.advanced-ip-scanner.com/

1.2 Raspberry Pi Imager. Raspberry Pi Imager est le moyen rapide et facile d’installer Raspberry Pi OS sur une carte microSD, prête à l’emploi avec votre Raspberry Pi :

https://www.raspberrypi.com/software/

1.3 PuTTY. Ce programme est un client SSH principalement utilisé pour se connecter à distance à des systèmes informatiques:

https://www.putty.org/

1.4 FilleZilla Client. C’est un programme de transfert de fichiers qui permet aux utilisateurs de gérer et de transférer des fichiers entre leur ordinateur local et une machine distante :

https://filezilla-project.org/

### 1.5 Téléchargement de carte sur Google Drive :

https://drive.google.com/file/d/1Afhucx_kdtul0cSf0_6vRhANw7dOtnIN/view?usp=sharing

## 2. Installation Raspberry Pi OS

2.1 Insérez la carte SD dans le lecteur de carte de votre ordinateur.

2.2 Ouvrir le logiciel Raspverry PI OS.

### 2.3 Choisir le bon OS


### 2.4 Choisir la carte microSD comme stockage


### 2.5.1 Configuration de l’OS

### 2.5.2 Activer le SSH et ajouter un Username et mot de passe

Sauvegarder l’identifiant et mot de passe pour l’étape Installation du logiciel sur Raspberry PI

### 2.5.3 Configurer la connexion au WiFi

1.Activer la connexion wLAN
2.Sélectionner le réseau local. Attention, le Raspberry Pi ne connecte pas au réseau de 5GHz
3.Entrer le mot du passe du réseau

### 2.5. Installer l’OS


# Installation du logiciel sur le Raspberry PI

## 1. Insérer la carte microSD dans le Raspberry Pi

## 2. Allumer le Raspberry Pi

## 3. Trouver l’IP du Raspberry Pi

### 3.1 Lancer le scan avec Advanced IP Scanner

### 3.2 Copier l’IP du Raspberry PI


## 4. Connection via SSH

### 4.1 Ouvrir puTTY.exe

### 4.2 Connection au Raspberry Pi


1. Coller l’IP du Raspberry Pi
2. Port 22 nécessaire

## 5. Téléchargement du logiciel

### 5.1 Connection au Raspberry avec les identifiants de l’étape Préparation du Raspberry Pi


### 5.2 Mettre à jour le Raspberry Pi OS en exécutant

sudo apt-get update
sudo apt-get upgrade

### 5.3 Cloner le git repository en exécutant

git clone https://github.com/Onyme13/Homemade_Glider_Tracker.git

5.4 Installer Pip et aller dans le fichier et installer toutes les bibliothèques python nécessaires en exécutant :

sudo apt install python3-pip pip –version

5.5 Après l’installation de pip, vous pouvez vérifier que pip est installé. Ensuite, installez les bibliothèques python nécessaires

cd Homemade_Glider_Tracker sudo python -m pip install -r requirements.txt

5.6 Transférez le fichier zippé de la carte à l’aide de FileZilla.
Drag and Drop le dossier de la carte zippé de l’étape Préparation du Raspberry Pi


1. IP du Raspberry PI
2. Identifiant
3. Mot de passe
4. Port 22
5. Connection


### 5.7 Décompressez le fichier en l’exécutant sur le Raspberry Pi en exécutant :

sudo apt install unzip
unzip tiles_OSM.zip

## 6. Activation du Touchscreen

### 6.1 Activer les connecteurs SPI

sudo raspi-config

6.2 Installer les fichiers nécessaire pour l’écran.

sudo rm -rf LCD-show
git clone https://github.com/MrYacha/LCD-show.git cd LCD-show
chmod LCD35-show

6.3 Finalement, le Raspberry Pi va redémarrer.

sudo ./LCD35-show

## 7. Ajout d’icône de lancement du logiciel sur le Desktop du Raspberry

Pi

### 7.1 Copie des données de l’icône sur le chemin du Desktop

cp Homemade_Glider_Tracker/launch.desktop ~/Desktop/

### 7.2 Ajout des droits d’exécution du script

sudo chmod +x Homemade_Glider_Tracker/startup.sh

# Assemblage du suiveur de vol

## Matériel

1. Module GPS - Whadda WPI430 Module GPS U-BLOX NEO-7M
2. Module Baromètre - DFRobot Gravity BMP388 Capteur de pression barométrique


3. Batterie PiSugar - PiSugar Pwnagotchi Batterie au lithium pour Raspberry Pi-Zero W/WH 1200 mAh


4. Arduino Micro (sans les pins/headers)
5. Câbles DuPont


6. Boîter imprimer en 3D (voir les étapes suivantes)

## 1.Impression du boîter et de son couvercle en 3D

Fichier STL pour l’impression

- Boîtier :
https://github.com/Onyme13/Homemade_Glider_Tracker/blob/main/3D%20STL%20file/case%20v0. 2.stl (https://github.com/Onyme13/Homemade_Glider_Tracker/blob/main/3D%20STL%20file/case%20v0.2.stl)
- Couvercle :
https://github.com/Onyme13/Homemade_Glider_Tracker/blob/main/3D%20STL%20file/cover%20v0 .4.stl (https://github.com/Onyme13/Homemade_Glider_Tracker/blob/main/3D%20STL%20file/cover%20v0.4.stl)

## 2. Assemblage des câbles du Dupont sur le module GPS


- RXD transmission câble jaune
- TXD transmission câble vert
- GND prise de terre câble noir
- VCC entrée 5 v câble rouge

## 3. Assemblage des câbles du Dupont sur le module barométrique

Souder les câbles Dupont aux entrées :
- VCC
- GND
- SDO
- CSB
- SDI
- SCK


## 4. Assemblage des câbles du GPS et baromètre au Arduino Micro

Souder les câbles du GPS et du baromètres au Arduino Micro comme suit :

Baromètre :
- VCC → +3.3V
- GND → GND
- SDO → 12
- CSB → 10
- SDI → 11
- SCK → 13

Module GPS :

- VCC → +5V
- GND → GND
- RXD → 9
- TXD → 8


## 5. Couper les pins du haut du Arduino Micro afin de gagner de la place dans le boitier

## 6.Branchez la batterie PiSugar sur le Raspberry Pi à l’aide des quatre vis fournies


Pour plus d’information suivre le manuel de branchage de la batterie PiSugar

### 6.1 Aligner correctement les pins de la batterie avec les pins du Raspberry Pi

### 6.2 Visser la batterie PiSugar au Raspberry Pi

## 7.Brancher le câble microUSB au Arduino Micro à l’entrée microUSB du Raspberry Pi Zero

## 8.Insérez délicatement le tout dans le boîter imprimé en 3D

8.1 Insérez en premier le Raspberry Pi Zero avec PiSugar et le câble microUSB comme suit. La carte microSD doit sortir par l’ouverture prévue à cette effet.


8.2 Connectez le câble miscoUSB au Arduino Micro. Et insérez le tout délicatement dans le boîtier, l’entrée male du câble GPS doit ressortir par le trou prévu à cet effet.

### 8.3 Connecter l’écran aux pins du haut droite du Raspberry Pi (encadrés en rouge)

### 8.4 Posez le couvercle imprimé en 3D

## 9.Visez les deux vis sur le côté du boîtier

Sur le côté gauche et droite. Il faut des vis de 2mm de diamètre et pas plus de 6mm de longueur

# Récupération des données de vols

## 1. Ouvrir FileZilla sur votre PC 2. Connection l’IP du Raspberry Pi avec ses identifiants 3. Drag and Drop le fichier d’enregistrement. Il se trouve dans Homemade_Glider_Tracker/data/mouvement_[YYYY-MM-DD].csv


# Tests

## 1er Test : À Pied

Le premier test à pied est un succès. Bien que le chemin tracé par le GPS ne soit pas particulièrement long, cela s'explique par la faible vitesse de déplacement de seulement 5 km/h. De manière attendue, la vitesse verticale n'a pas varié durant ce test, ce qui est tout à fait conforme aux attentes. Le GPS fonctionne malgré le fait qu’il a été testé en zone urbaine (Petit-Lancy). Les immeubles d’habitations pourraient bloquer la plupart des satellites de réception, mais le chemin est indiqué par le GPS est fidèle à la réalité du trajet du test.

Le trajet indiqué sur la photo de l’écran est court, mais le logiciel est calibré pour des parcours sur des grandes distances. Ce dernier mets à jour la position du planeur uniquement lorsqu’un certain seuil est dépassé.

Nous pouvons voir que les positions GPS sont réparties par « clusters ». Le fait que le test a été réaliser en zone urbaine pourrait expliquer cela. Les immeubles d’habitations auraient pu bloquer quelques signaux satellites.

Ces résultats confirment la précision et la fiabilité du GPS, même dans des conditions de déplacement à faible vitesse.


## 2ème Test : En Vélo

Le test à vélo a produit des résultats similaires, avec un suivi de la position et de l'altitude. Comme pour le test à pied, quelques pertes de signal GPS sporadiques ont été observées. Il est important de souligner que ces perturbations pourraient être attribuées à l'environnement urbain dans lequel le test a été effectué (quartier d’Onex).

Malgré ces perturbations occasionnelles, le tracker a continué à fonctionner de manière fiable dans des conditions exigeantes. Ces résultats prouvent qu’avec une plus grande vitesse, le tracker fonctionne tout de même. Un test en vol est à suivre.


## 3ème Test : En Avion

La dernière phase de test a placé le tracker de vol dans son élément naturel : l'aviation légère. Intégré à un avion moteur léger, le dispositif a été évalué lors de vols réels en avion.

Lors du test en avion moteur, le tracker de vol a été soumis à une épreuve en survolant depuis l’aérodrome d’Annemasse, la région de la Roche-sur-Foron, puis Bonneville, à une altitude de 5000 pieds. Comme nous pouvons le voir sur le report de l'enregistrement du vol sur GPS Visualizer, il y a eu une perte de signal GPS au-dessus de la Roche-sur-Foron qui n'a été retrouvée par la suite. Cependant, malgré cette perte temporaire de données GPS, l'altimètre du tracker de vol a continué à indiquer avec précision l'altitude actuelle. Il est important de noter que l’indicateur de vitesse vertical du tracker indiquait des résultats juste.

La calibration automatique de l’altimètre, grâce l’altitude donné par le GPS, est correcte. Celui-ci indiquait une pression de 1020hPa ce qui était la pression du jour dans la région (7 septembre 2023).
Une caractéristique du tracker de vol est sa capacité de calibration. Il utilise les données de l'altitude du GPS en comparant les mesures répétées (environ 20 fois) pour déterminer une altitude fiable, et ainsi une pression atmosphérique locale.
Cette méthodologie de calibration assure une précision optimale dans le suivi de l'altitude, même dans des situations auxquelles la réception GPS peut être intermittente, comme cela a été observé lors du vol au-dessus de la Roche-sur-Foron.

Ces résultats sont très encourageants, car ils montrent que le tracker de vol est équipé pour maintenir des informations cruciales, telles que l'altitude, même en cas de perturbation de la réception GPS.


## Conclusion des Tests


Les phases de test diversifiées ont solidement confirmé la fonctionnalité et la performance du tracker de vol. Qu'il s'agisse du déplacement à pied, à vélo ou en avion, le dispositif a fait preuve d'une collecte de données viables. Le choix des composants, notamment le Raspberry Pi Zero W et l'Arduino Micro, a assuré une flexibilité essentielle.

Les futurs développements se concentreront sur l'optimisation logiciel continue du tracker de vol et sur les pertes de signaux GPS occasionnels.

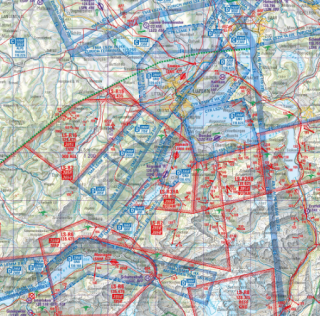
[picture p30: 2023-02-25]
images/map.png

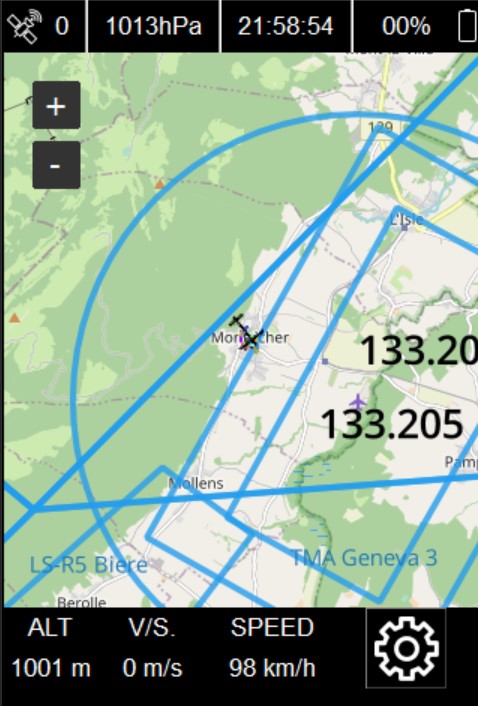
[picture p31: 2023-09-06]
images/readme/log2.jpg

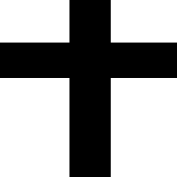
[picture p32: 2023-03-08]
images/glider2.png

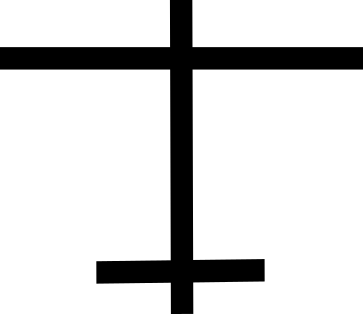
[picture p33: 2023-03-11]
images/glider.png

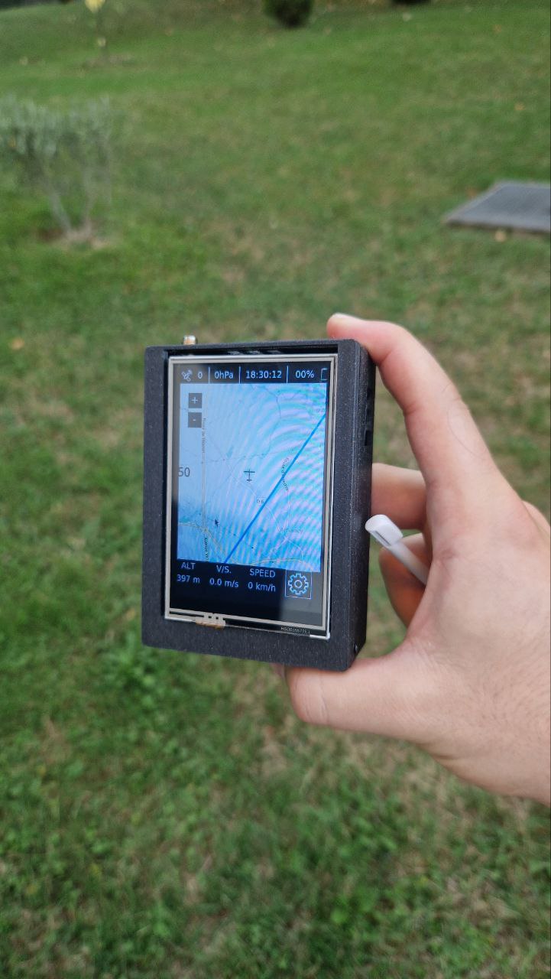
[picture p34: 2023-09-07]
images/readme/art3.jpg

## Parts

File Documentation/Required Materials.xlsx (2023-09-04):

Component |  | Price | Source
Raspberry Pi Zero W |  | €29.90 | digitec.ch
GPS module | (Whadda WPI430 Module GPS U-BLOX NEO-7M) | €36.20 | digitec.ch
Barometer | (DFRobot Gravity BMP388) | €7.80 | gotronic.fr
Arduino Micro |  | €25.80 | digitec.ch
Cables Dupont |  | €0.80 | AliExpress
Cable micro USB to micro USB |  | €2.23 | AliExpress
Joy-It screen 3.5'' | (Joy-it Module d'affichage Raspberry Pi® JT3.5TR) | €27.90 | digitec.ch
PiSugar Battery 1200 mAh | (PiSugar Pwnagotchi Lithium Battery for Raspberry Pi-Zero W) | €29.99 | amazon.fr
 | TOTAL | €160.62

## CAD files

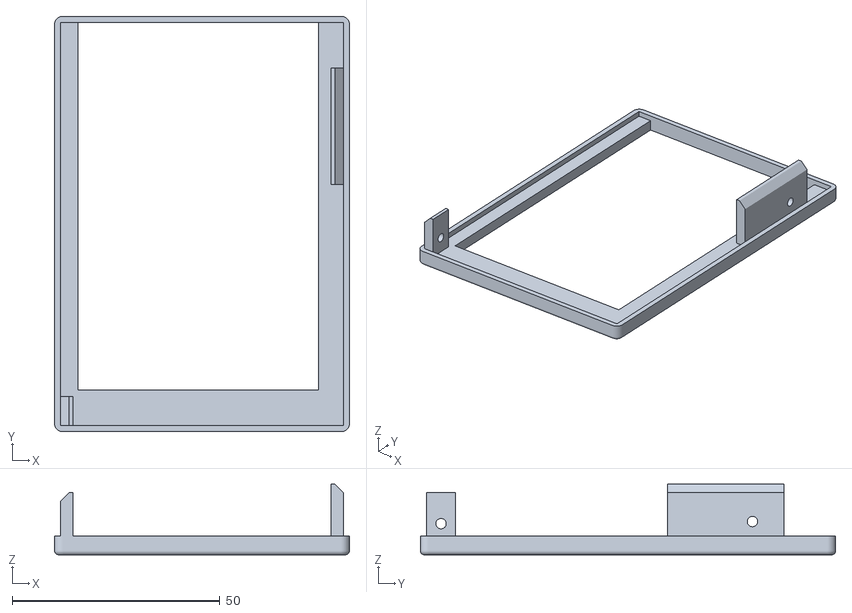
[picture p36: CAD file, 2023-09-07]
3D STL file/cover v0,7.stl
71.0 x 100.0 x 17.0

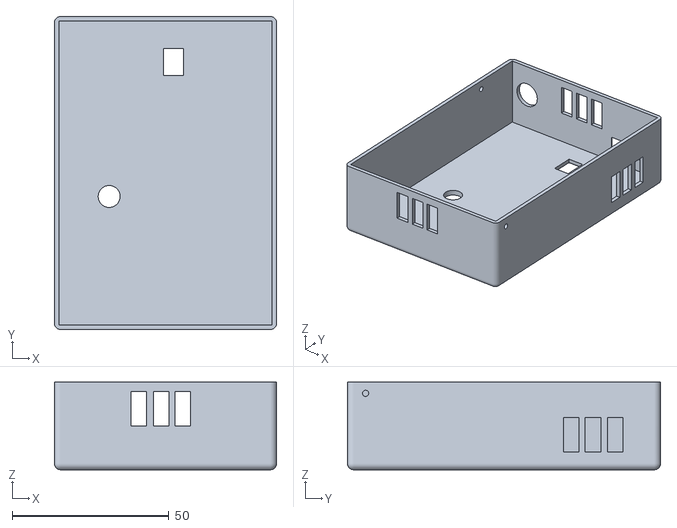
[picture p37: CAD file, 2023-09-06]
3D STL file/case v0.3.stl
71.0 x 100.0 x 28.0

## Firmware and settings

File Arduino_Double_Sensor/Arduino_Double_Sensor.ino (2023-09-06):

/*
Code du Arduino pression barométrique et localisation. Latitude, longitude, altitude.

Sortie: "latitude,longitude,vitesse,altitude, altitude pression"
système métriques

Testé avec Arduino Uno et Arduino Micro

*/

#include <SPI.h>
#include <Adafruit_Sensor.h>
#include "Adafruit_BMP3XX.h"
#include <TinyGPSPlus.h>   
#include <SoftwareSerial.h>


//SoftwareSerial ss(3, 2); // TX, RX, for Arduino Uno ONLY !
SoftwareSerial ss(9, 8); // RXD, TXD --> for Arduino Micro
TinyGPSPlus gps;
Adafruit_BMP3XX bmp;

//Wiring for the barometer
#define BMP_SCK 13 // SCK
#define BMP_MISO 6 // SDO
#define BMP_MOSI 11 // SDI
#define BMP_CS 10 // CSB



#define SEALEVELPRESSURE_HPA (1013.25)




void setup() {
  Serial.begin(9600);
  ss.begin(9600);

  while(!Serial){
  }
  
  //commencer le setup pour le baromètre    
  if (! bmp.begin_SPI(BMP_CS, BMP_SCK, BMP_MISO, BMP_MOSI)) {  
     Serial.println("Could not find a valid BMP3 sensor, check wiring!");
    while (1);
  }

  bmp.setTemperatureOversampling(BMP3_OVERSAMPLING_8X);
  bmp.setPressureOversampling(BMP3_OVERSAMPLING_4X);
  bmp.setIIRFilterCoeff(BMP3_IIR_FILTER_COEFF_3);
  bmp.setOutputDataRate(BMP3_ODR_50_HZ);


}
void loop() {
  while (ss.available() > 0) 
    if (gps.encode(ss.read())){
      gps_loc();
    }
  vert_speed();
  Serial.println();
  delay(250);
}

//Function de sortie
//-----------------------------------------------------------------------------------------------//

void vert_speed(){
  if (! bmp.performReading()) {
  Serial.println("Failed to perform reading :(");
  return;
  }
  Serial.print(bmp.readAltitude(SEALEVELPRESSURE_HPA));

}

void gps_loc(){
    if (gps.location.isValid()){
      Serial.print(gps.location.lat(), 8);
      Serial.print(","); 
      Serial.print(gps.location.lng(), 8);
      Serial.print(",");
      Serial.print(gps.speed.kmph());
      Serial.print(",");
      Serial.print(gps.altitude.meters());  
      Serial.print(",");
      Serial.print(gps.satellites.value());  
      Serial.print(","); 
  }

}

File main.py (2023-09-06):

"""Main file that processes raw data from the Arduino"""

import serial
from datetime import datetime
import itertools
import time
from constants import *


#arduinoSerial = serial.Serial('COM4', 9600) #For Windows
arduinoSerial = serial.Serial('/dev/ttyACM0', 9600) #For Linux


previous_altitude = 0
previous_time = 0
altitudeBucket = []
altGPSArray = []
heightCalibrated = 0
calibrated = False  
localQNH = 0

#If the GPS altitude is similar 20 times in raw. Adapt the barometer to local QNH
def adapt_local_pressure(altGPS,alt):
    global localQNH
    global heightCalibrated
    global calibrated


    altGPSArray.append(altGPS)

    if len(altGPSArray) > 20:
        altGPSArray.pop(0)
        if all(abs(x - y) < 3.5 for x, y in itertools.combinations(altGPSArray, 2) if x != 0.0):
            localQNH = SEALEVELPRESSURE + ((sum(altGPSArray) / len(altGPSArray)) - alt) * METERSOFAIRHETCOPASCAL
            heightCalibrated = round((localQNH - SEALEVELPRESSURE) * HETCOPASCALMETERSOFAIR, 1)
            calibrated = True  

#Verical speed calculated from a Delta between time and height
def vertical_speed(alt):
    global previous_altitude, previous_time
    current_time = time.time()
    delta_time = current_time - previous_time
    altitude_difference = alt - previous_altitude
    vertical_speed = altitude_difference / delta_time
    
    # Update previous values for the next iteration
    previous_altitude = alt
    previous_time = current_time
    
    vertical_speed = round(vertical_speed, 1)
    
    # If the vertical speed is too small, set it to 0.0
    if vertical_speed == -0.0 or vertical_speed == 0.1 or vertical_speed == -0.1 or vertical_speed == 0.2 or vertical_speed == -0.2:
        vertical_speed = 0.0
    return vertical_speed

#Transform raw data into JSON
def data():
    #time.sleep(1)
    while arduinoSerial.inWaiting() == 0:
        pass
    dataString = arduinoSerial.readline().decode('utf-8')
    dataArray = dataString.replace('\r\n', '').split(',')

    localtime = datetime.now().strftime("%H:%M:%S.%f")[:-3]
    returnDict = {
        "time": localtime,
        "localQNH": 0,
        "lat": 0,
        "long": 0,
        "speed": 0,
        "altGPS": 0,
        "sat": 0,
        "vert": 0,
        "alt": 0
    }

    if len(dataArray) == 1:
        altitude = float(dataArray[0])
        vert_speed = vertical_speed(altitude)
        if calibrated:
            altitude += heightCalibrated
        returnDict.update({"vert": vert_speed, "alt": altitude, "localQNH":localQNH})
    elif len(dataArray) >= 5:
        latitude = float(dataArray[0]) 
        longitude = float(dataArray[1])
        speed = float(dataArray[2])
        altitudeGPS = float(dataArray[3])
        satellites = float(dataArray[4])
        altitude = float(dataArray[-1])

        vert_speed = vertical_speed(altitude)

        if not calibrated:
            adapt_local_pressure(altitudeGPS, altitude)

        if calibrated:
            altitude += heightCalibrated

        returnDict.update({
            "lat": latitude,
            "long": longitude,
            "speed": speed,
            "altGPS": altitudeGPS,
            "sat": satellites,
            "vert": vert_speed,
            "alt": altitude,
            "localQNH":localQNH
        })
    print(returnDict)
    return returnDict


#while True:
#    data()

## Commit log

2023-02-27 FIX arduino code
2023-02-28 FIX window close bug
    [GUI.py]
2023-03-04 FIX update data with tkinter
    [GUI_tkinter.py]
2023-03-05 ADD realtime data updating and threading
2023-03-05 FIX commented threading
2023-03-11 FIX orientation of glider icon
    [GUI_tkinter.py]
2023-03-31 ADD file with positions functions
    [last_pos.csv]
2023-04-05 MODIFY tracker positions
    [last_pos.csv]
2023-04-10 ADD sql command filter zoom levels
2023-06-19 MODIFY store tiles printing comments
2023-06-19 FIX path for csv
    [positions_functions.py]
2023-07-01 Revert "MODIFY trying to improve perf."
    This reverts commit 25417e9115c4e296e689ba8746012715eef49ae0.
    [GUI_tkinter.py, main.py]
2023-07-05 Feature of drawing track (incomplete)
2023-07-13 MODIFY add kill button
2023-08-30 ADD STL file for 3d printing
    [case v0.2.stl, cover v0.4.stl]
2023-09-04 MODIFY write names of material
    [Required Materials.xlsx]
2023-09-06 NEW cover version
    [case v0.2.stl, case v0.3.stl, cover v0.4.stl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]
2023-09-06 new stl file
    [cover v0.5.stl, cover v0.6.stl]
2023-09-07 ADD new cover file
    [cover v0,7.stl, cover v0.6.stl]
2023-09-08 ADD powerpoint presentation
